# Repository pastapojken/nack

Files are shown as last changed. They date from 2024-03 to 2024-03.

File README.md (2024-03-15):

# nack
nack keyboard - uses [**QMK**](https://github.com/qmk/qmk_firmware)  
A ISO-friendly, 13x4 keyboard. It has hardware support for basically all the bells and whistles that qmk can provide!

You like my work? Feel free to donate :)  
[donation](https://www.paypal.com/donate?hosted_button_id=YEAQ4WGKJKYQQ)

nack_rgb nack with full RGB

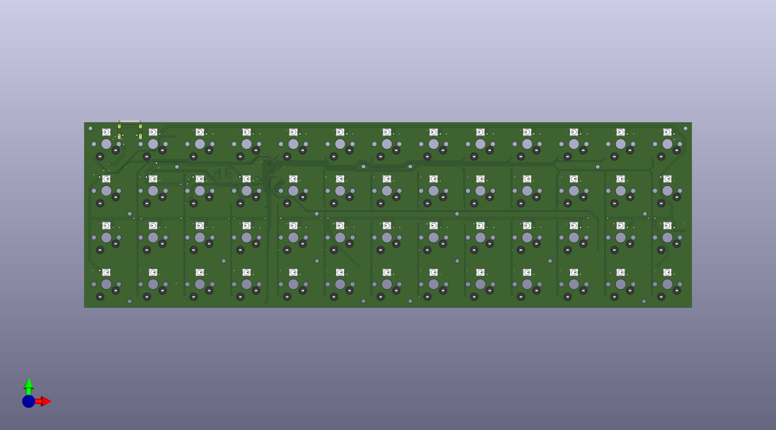
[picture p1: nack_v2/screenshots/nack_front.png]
nack_PCB_front nack PCB (front)


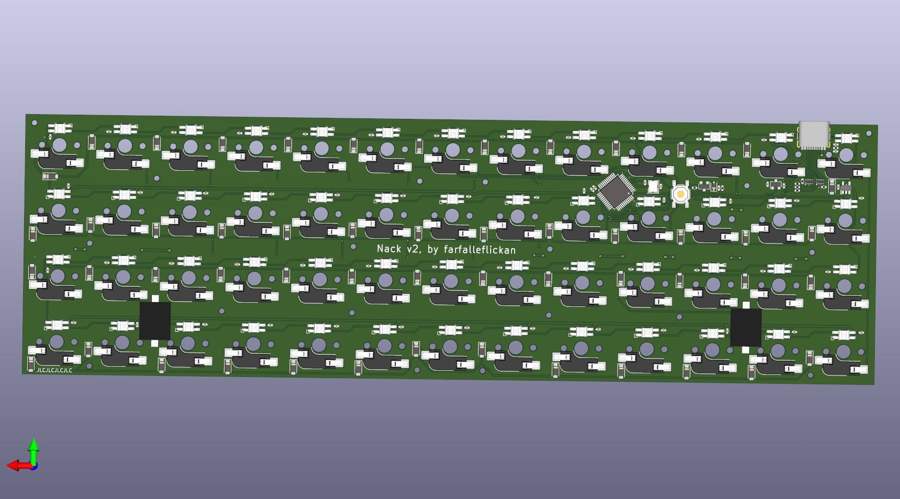
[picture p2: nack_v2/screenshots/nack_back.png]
nack_PCB_back nack PCB (back)


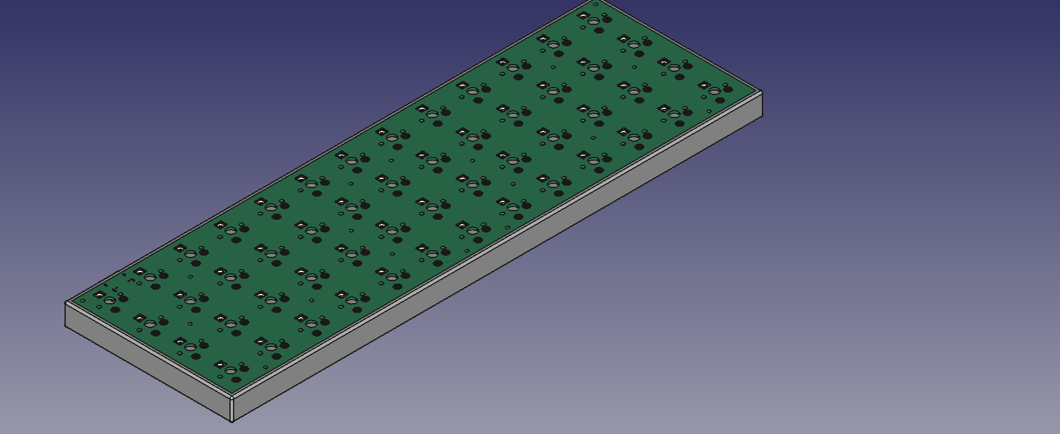
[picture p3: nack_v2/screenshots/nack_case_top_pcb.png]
nack_case_front nack case front


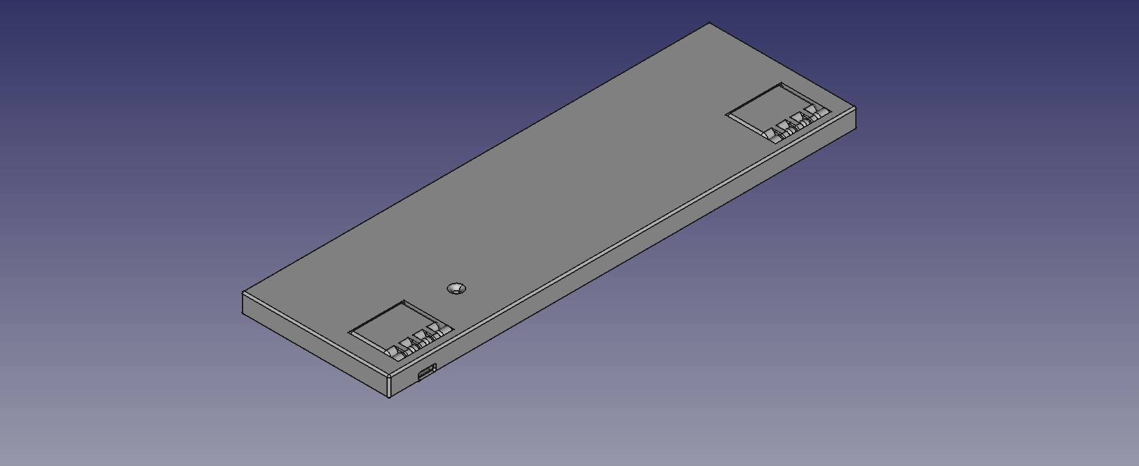
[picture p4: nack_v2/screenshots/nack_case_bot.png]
nack_case_back nack case back


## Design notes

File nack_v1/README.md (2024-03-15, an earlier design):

# nack
nack keyboard - uses [**QMK**](https://github.com/qmk/qmk_firmware)  
A ISO-friendly, 13x4 keyboard. It has hardware support for basically all the bells and whistles that qmk can provide!

You like my work? Feel free to donate :)  
[donation](https://www.paypal.com/donate?hosted_button_id=YEAQ4WGKJKYQQ)

nack_rgb nack with full RGB

nack_PCB nack PCB

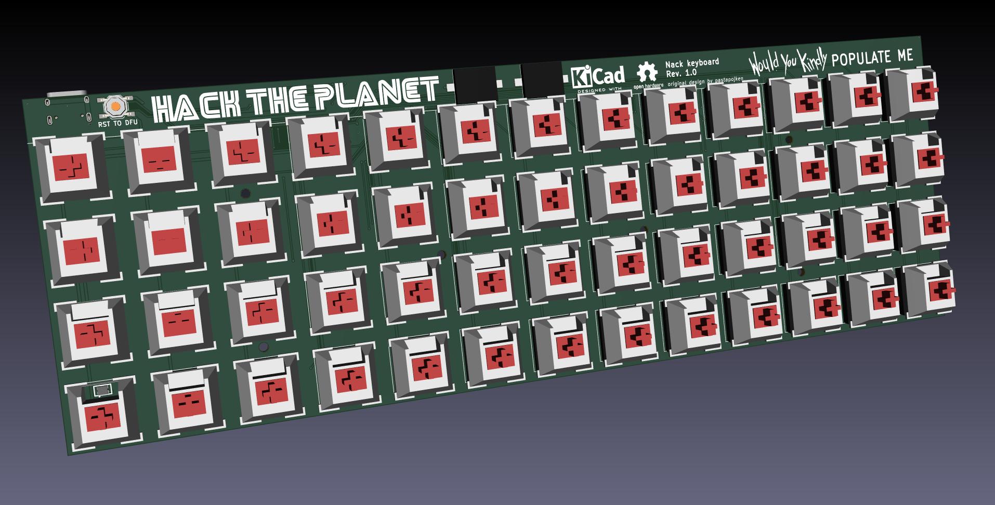
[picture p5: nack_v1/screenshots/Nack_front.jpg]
nack_front nack front


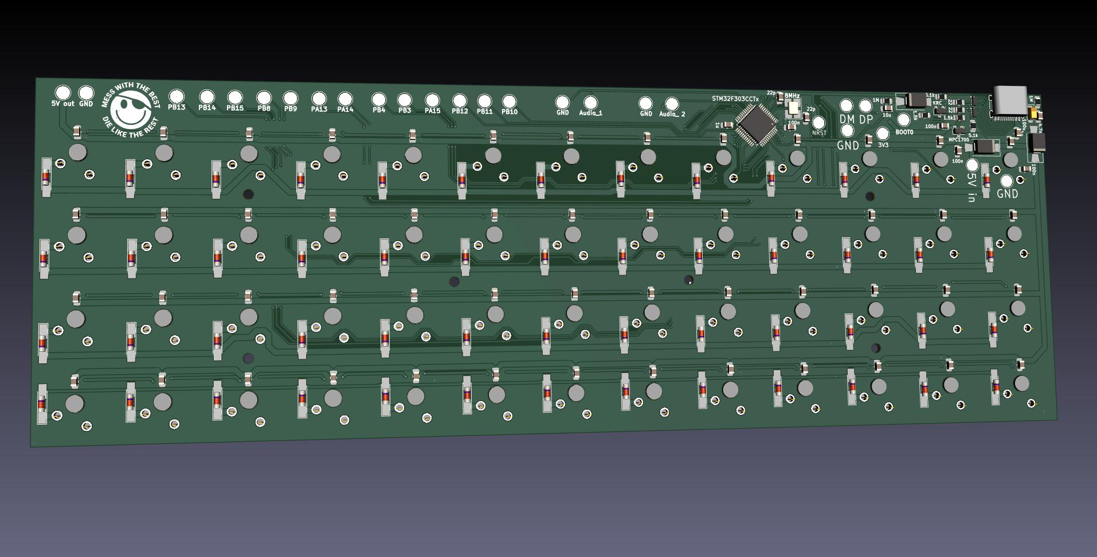
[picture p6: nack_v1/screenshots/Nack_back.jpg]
nack_back nack back


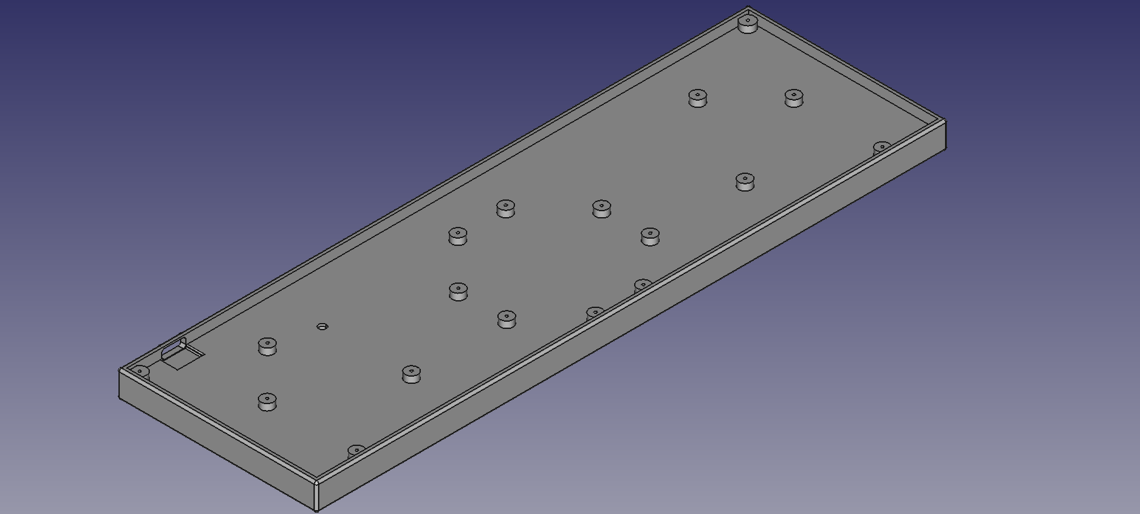
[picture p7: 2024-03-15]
nack_v2/screenshots/nack_case_top.png

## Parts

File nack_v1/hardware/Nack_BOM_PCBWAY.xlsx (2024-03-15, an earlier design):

 |  |  | Nack BOM
Item # | *Designator | *Qty | Manufacturer | *Mfg Part # | Description / Value | *Package/Footprint | Type | Your Instructions / Notes
1 | C53 C56 | 2 | Samsung Electro-Mechanics | CL21C220JBANNNC | 50V, 22pF, ceramic capacitor, 0805 | 0805 | SMD | Any manufacturer can be used, as long as the components has the same values
2 | C57 C55 C54 C1 C2 C3 C4 C5 C6 C7 C8 C9 C10 C11 C12 C13 C14 C15 C16 C17 C18 C19 C20 C21 C22 C23 C24 C25 C26 C27 C28 C29 C30 C31 C32 C33 C34 C35 C36 C37 C38 C39 C40 C41 C42 C43 C44 C45 C46 C47 C48 C49 C50 C51 C52 C60 | 56 | Samsung Electro-Mechanics | CL21B104KBCNNNC | 50V, 100nF, ceramic capacitor, 0805 | 0805 | SMD | Any manufacturer can be used, as long as the components has the same values
3 | C58 C59 | 2 | Samsung Electro-Mechanics | CL21B105KBFNNNE | 50V, 1uF, ceramic capacitor, 0805 | 0805 | SMD | Any manufacturer can be used, as long as the components has the same values
4 | C61 | 1 | Samsung Electro-Mechanics | CL21A106KQFNNNE | 6.3V, 10uF, ceramic capacitor, 0805 | 0805 | SMD | Any manufacturer can be used, as long as the components has the same values
5 | C62 | 1 | KEMET | T490A107M006ATE800 | 6.3V, 100uF, tantalum capacitor, KEMET-A/EIA-3216 | KEMET-A/EIA-3216 | SMD | Any manufacturer can be used, as long as the components has the same values
6 | C63 | 1 | CCTC | TCC0805X7R472K500DT | 50V, 4.7nF, ceramic capacitor, 0805 | 0805 | SMD | Any manufacturer can be used, as long as the components has the same values
7 | D1 D2 D3 D4 D5 D6 D7 D8 D9 D10 D11 D12 D13 D15 D16 D17 D18 D19 D20 D21 D22 D23 D24 D25 D26 D27 D28 D29 D30 D31 D32 D33 D34 D35 D36 D37 D38 D39 D40 D41 D42 D43 D44 D45 D46 D47 D48 D49 D50 D51 D52 D53 | 52 | LGE | LL4148 | LL4148, MiniMELF | MiniMELF | SMD
8 | D55 D54 D14 | 3 | Microdiode Electronics | SL54B | 40V, SL54B, SMB/DO-214AA | SMB/DO-214AA | SMD
9 | D56 D57 | 2 | Texas Instruments | TPD4E02B04DQAR | TPD4E02B04DQAR, USB ESD protection diode, uSON-10 | uSON-10 | SMD
10 | J3 | 1 | SHOU HAN | TYPE-C16PIN | USB-C receptacle with only USB2.0, mixed SMD&TH | SMD | SMD
11 | LED52 LED51 LED50 LED49 LED48 LED47 LED46 LED45 LED44 LED43 LED41 LED40 LED26 LED25 LED24 LED23 LED22 LED21 LED20 LED19 LED18 LED17 LED16 LED15 LED14 LED39 LED38 LED37 LED36 LED35 LED34 LED33 LED32 LED31 LED30 LED29 LED28 LED27 LED13 LED12 LED11 LED10 LED9 LED8 LED7 LED6 LED5 LED4 LED3 LED2 LED1 LED42 | 52 | Worldsemi | WS2812C-2020 | WS2812C LED, 2022 | 2022 | SMD
12 | LS2 LS1 | 2 | KELIKING | KLJ-1102 | NO piezo, size 11mm x 9mm, SMD-11*9*1.7 | SMD-11*9*1.7 | SMD
13 | Q1 | 1 | KEC Semicon | KRC106S-RTK/P | 50V, 200mW, Pre-Biased 100mA NPN transistor, SOT-23-3 | SOT-23 | SMD
14 | R1 R8 | 2 | Uniroyal Elec | 0805WAD | 1MΩ, ±1%, 1/8W, 0805 | 0805 | SMD | Any manufacturer can be used, as long as the components has the same values
15 | R3 R2 | 2 | Uniroyal Elec | 0805WAD | 5.1kΩ, ±1%, 1/8W, 0805 | 0805 | SMD | Any manufacturer can be used, as long as the components has the same values
16 | R5 R4 | 2 | Uniroyal Elec | 0805WAD | 22Ω, ±1%, 1/8W, 0805 | 0805 | SMD | Any manufacturer can be used, as long as the components has the same values
17 | R6 R7 | 2 | Uniroyal Elec | 0805WAD | 1.5kΩ, ±1%, 1/8W, 0805 | 0805 | SMD | Any manufacturer can be used, as long as the components has the same values
18 | U1 | 1 | STMicroelectronics | STM32F303CCT6 | STM32F303CCT6, microcontroller, LQFP-48_7x7mm_P0.5mm | LQFP-48 | SMD
19 | U2 | 1 | HTC Korea TAEJIN Tech | LM1108SF-3.3 | LM1108SF, linear regulator IC, 3.3V, SOT-23-3 | SOT-23 | SMD
20 | Y1 | 1 | KDS Daishinku | 1C208000CC0AA | 8MHz, ±30ppm, 8pF, 400Ω, SMD-3225 | 3225 | SMD | Any manufacturer can be used, as long as the components has the same values
 |  | 187

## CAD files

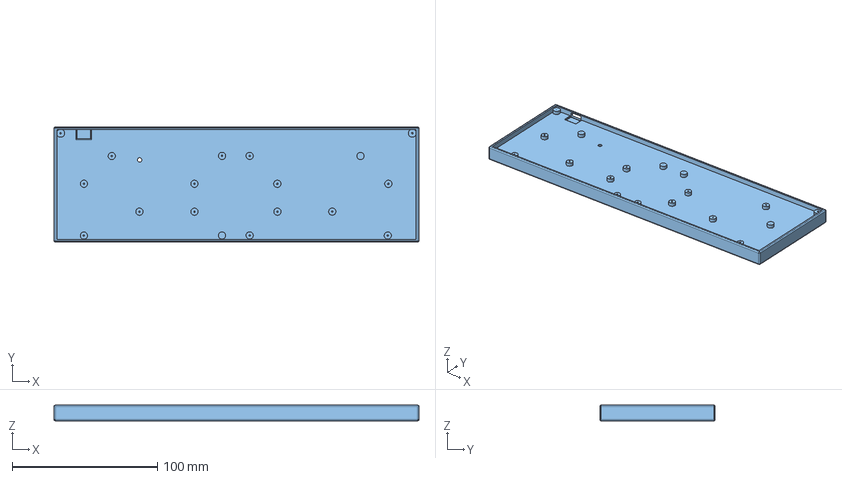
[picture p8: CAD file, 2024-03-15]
nack_v2/case/nack.FCStd
251.6 x 79.6 x 10.8 mm

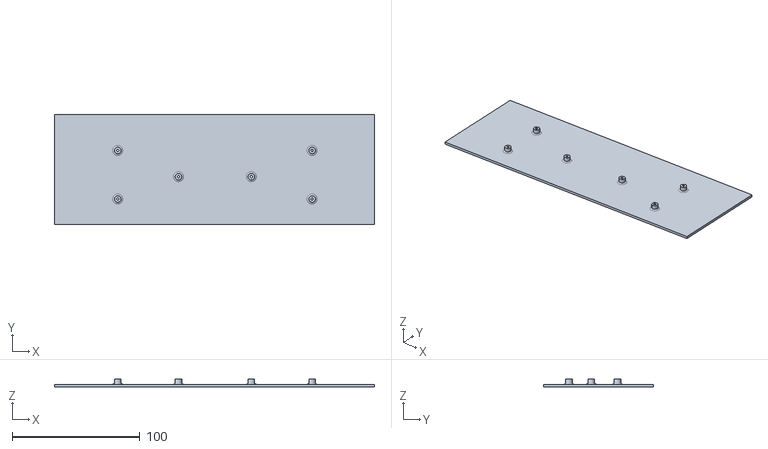
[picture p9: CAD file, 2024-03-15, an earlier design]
nack_v1/case/nackPlateBot.stl
250.9 x 86.5 x 6.00

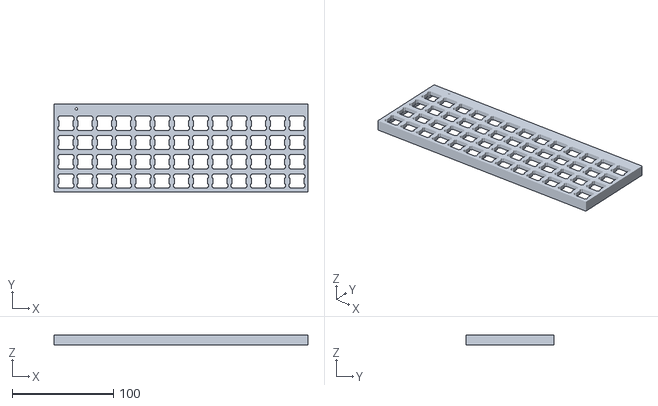
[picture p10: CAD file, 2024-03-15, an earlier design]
nack_v1/case/nackPlateTop.stl
251.3 x 86.9 x 10.2

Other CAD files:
nack_v1/case/nack_case.scad

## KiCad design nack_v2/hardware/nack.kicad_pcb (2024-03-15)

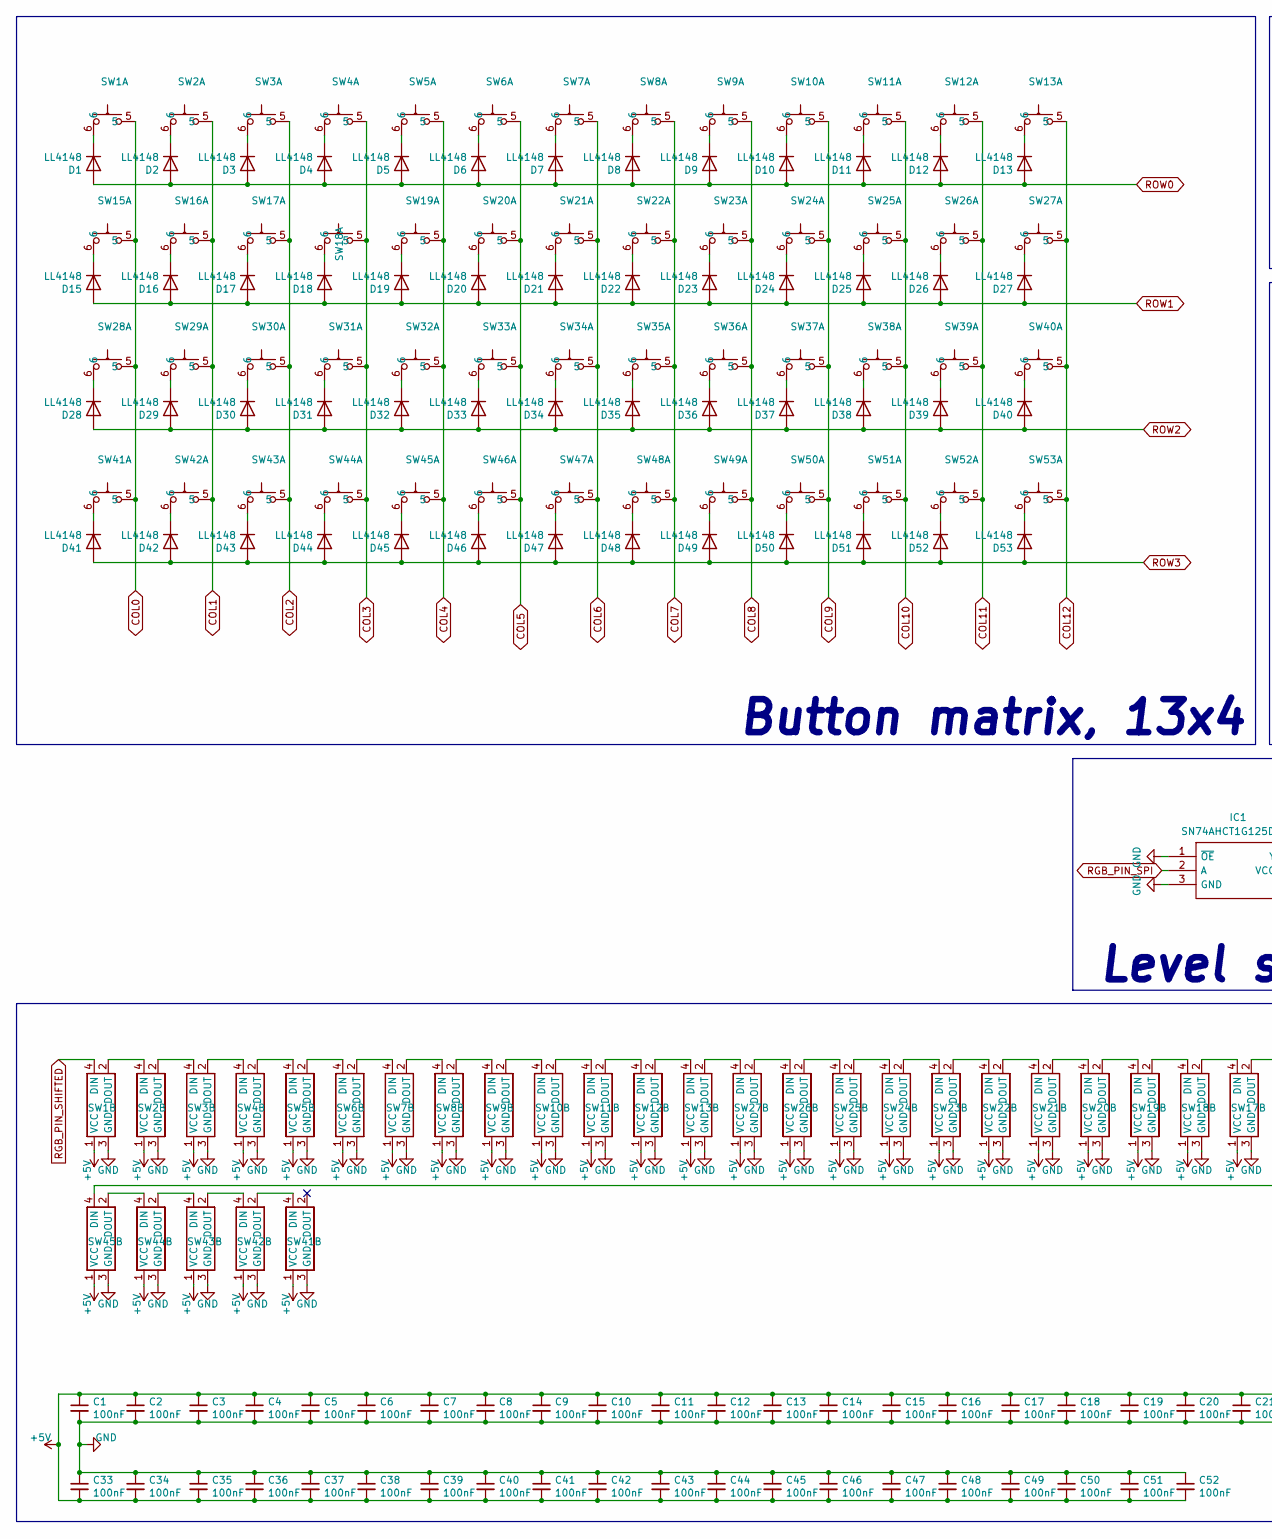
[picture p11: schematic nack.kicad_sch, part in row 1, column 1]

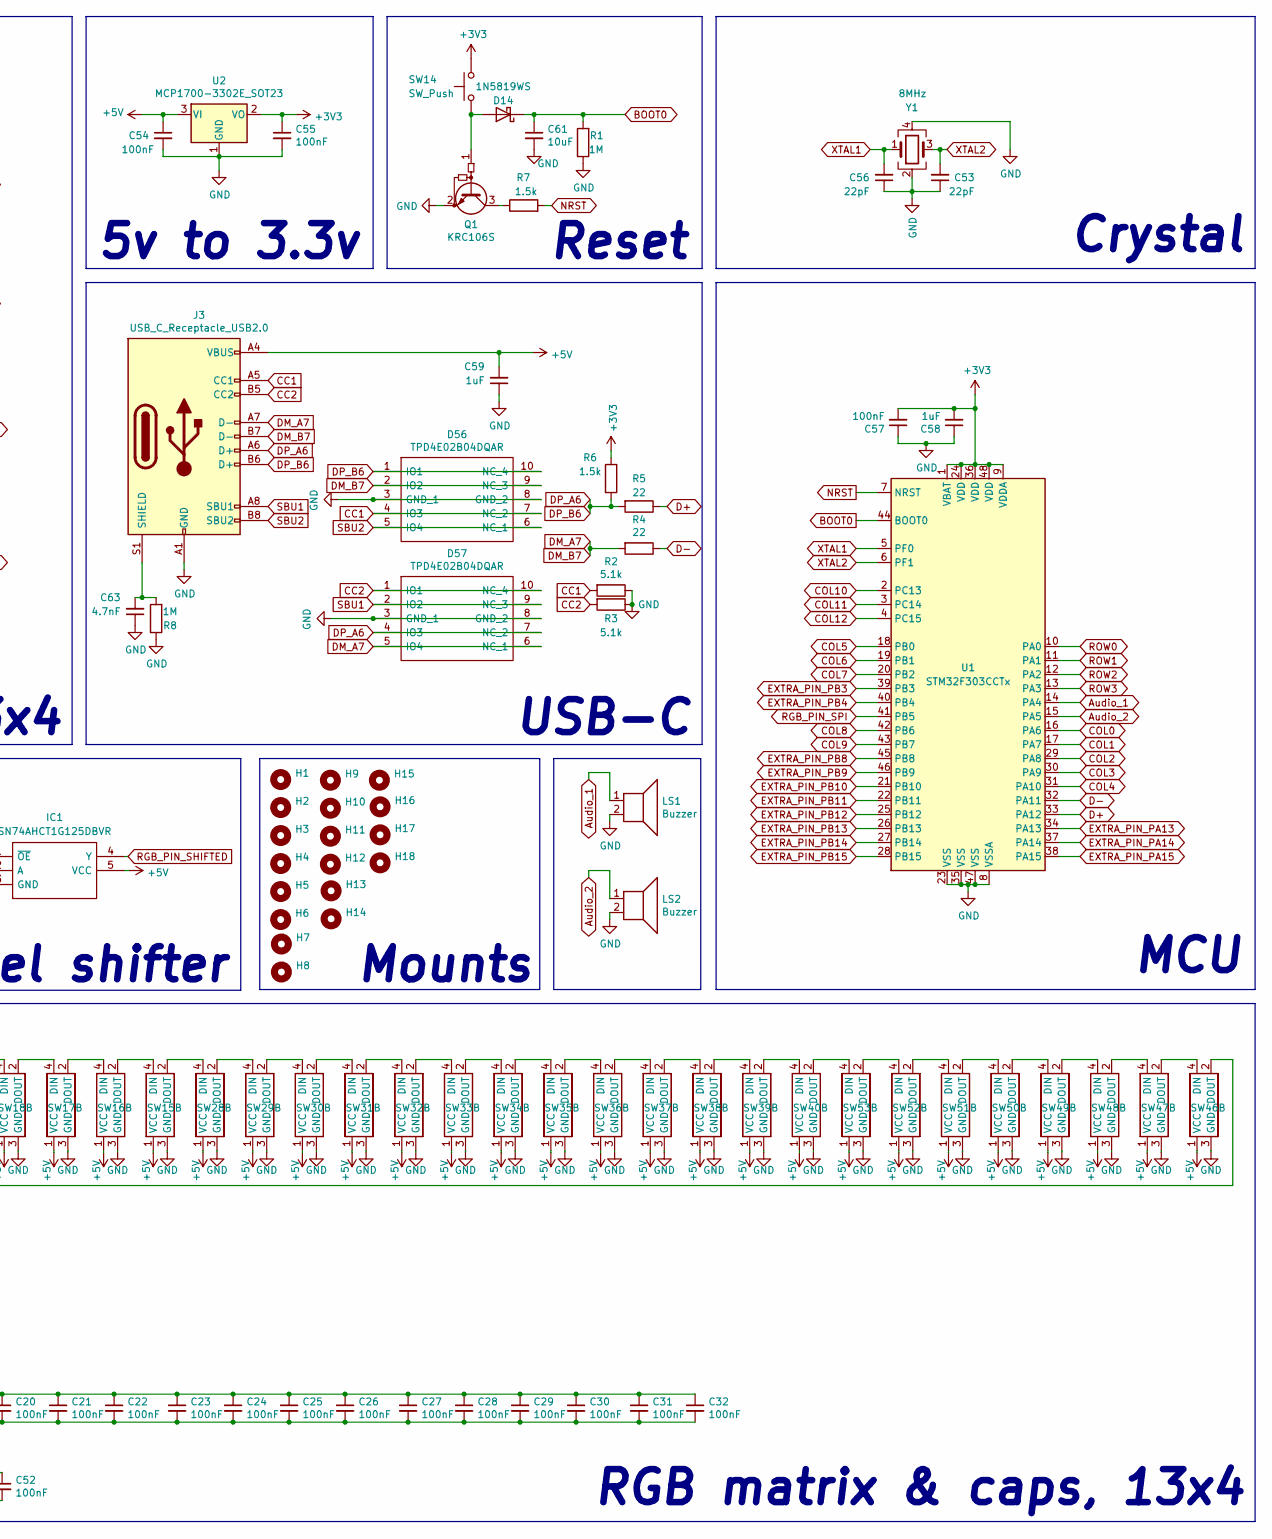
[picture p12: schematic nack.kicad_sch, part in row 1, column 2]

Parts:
C1, C2, C3, C4, C5, C6, C7, C8, C9, C10, C11, C12, C13, C14, C15, C16, C17, C18, C19, C20, C21, C22, C23, C24, C25, C26, C27, C28, C29, C30, C31, C32, C33, C34, C35, C36, C37, C38, C39, C40, C41, C42, C43, C44, C45, C46, C47, C48, C49, C50, C51, C52, C54, C55, C57: 100nF; C_0402_1005Metric
C53, C56: 22pF; C_0402_1005Metric
C58, C59: 1uF; C_0402_1005Metric
C61: 10uF; C_0402_1005Metric
C63: 4.7nF; C_0402_1005Metric
D1, D2, D3, D4, D5, D6, D7, D8, D9, D10, D11, D12, D13, D15, D16, D17, D18, D19, D20, D21, D22, D23, D24, D25, D26, D27, D28, D29, D30, D31, D32, D33, D34, D35, D36, D37, D38, D39, D40, D41, D42, D43, D44, D45, D46, D47, D48, D49, D50, D51, D52, D53: LL4148; D_SOD-123
D14: 1N5819WS; D_SOD-323
D56, D57: TPD4E02B04DQAR; DQA(R-PUSON-N10); Manufacturer_Part_Number TPD4E02B04DQAR; Mouser Part Number 595-TPD4E02B04DQAR
H1, H2, H3, H4, H5, H6, H7, H8, H9, H10, H11, H12, H13, H14, H15, H16, H17, H18: MountingHole; MountingHole_M1.4
IC1: SN74AHCT1G125DBVR; SOT95P280X145-5N; Manufacturer_Part_Number SN74AHCT1G125DBVR; Mouser Part Number 595-SNAHCT1G125DBVR
J3: USB_C_Receptacle_USB2.0; USB_C_Receptacle
LS1, LS2: Buzzer; KLJ-1102
Q1: KRC106S; SOT-23
R1, R8: 1M; R_0402_1005Metric
R2, R3: 5.1k; R_0402_1005Metric
R4, R5: 22; R_0402_1005Metric
R6, R7: 1.5k; R_0402_1005Metric
SW1, SW2, SW3, SW4, SW5, SW6, SW7, SW8, SW9, SW10, SW11, SW12, SW13, SW28, SW29, SW30, SW31, SW32, SW33, SW34, SW35, SW36, SW37, SW38, SW39, SW40: SW_Hotswap_MX; SW_Cherry_MX_Hotswap_RevLED_flipped
SW14: SW_Push; SW_SPST_TL3342
SW15, SW16, SW17, SW18, SW19, SW20, SW21, SW22, SW23, SW24, SW25, SW26, SW27, SW41, SW42, SW43, SW44, SW45, SW46, SW47, SW48, SW49, SW50, SW51, SW52, SW53: SW_Hotswap_MX; SW_Cherry_MX_Hotswap_RevLED
U1: STM32F303CCTx; LQFP-48_7x7mm_P0.5mm; LCSC C81523
U2: MCP1700-3302E_SOT23; SOT-23
Y1: 8MHz; Crystal_SMD_3225-4Pin_3.2x2.5mm; LCSC C253751

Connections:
+3V3: C55.1, C57.2, C58.2, R6.1, SW14.2, U1.1 (VBAT), U1.9 (VDDA), U1.24 (VDD), U1.36 (VDD), U1.48 (VDD), U2.2 (VO)
+5V: C1.1, C2.1, C3.1, C4.1, C5.1, C6.1, C7.1, C8.1, C9.1, C10.1, C11.1, C12.1, C13.1, C14.1, C15.1, C16.1, C17.1, C18.1, C19.1, C20.1, C21.1, C22.1, C23.1, C24.1, C25.1, C26.1, C27.1, C28.1, C29.1, C30.1, C31.1, C32.1, C33.2, C34.2, C35.2, C36.2, C37.2, C38.2, C39.2, C40.2, C41.2, C42.2, C43.2, C44.2, C45.2, C46.2, C47.2, C48.2, C49.2, C50.2, C51.2, C52.2, C54.1, C59.2, IC1.5 (VCC), J3.A4 (VBUS), J3.A9 (VBUS), J3.B4 (VBUS), J3.B9 (VBUS), SW1.1 (VCC), SW2.1 (VCC), SW3.1 (VCC), SW4.1 (VCC), SW5.1 (VCC), SW6.1 (VCC), SW7.1 (VCC), SW8.1 (VCC), SW9.1 (VCC), SW10.1 (VCC), SW11.1 (VCC), SW12.1 (VCC), SW13.1 (VCC), SW15.1 (VCC), SW16.1 (VCC), SW17.1 (VCC), SW18.1 (VCC), SW19.1 (VCC), SW20.1 (VCC), SW21.1 (VCC), SW22.1 (VCC), SW23.1 (VCC), SW24.1 (VCC), SW25.1 (VCC), SW26.1 (VCC), SW27.1 (VCC), SW28.1 (VCC), SW29.1 (VCC), SW30.1 (VCC), SW31.1 (VCC), SW32.1 (VCC), SW33.1 (VCC), SW34.1 (VCC), SW35.1 (VCC), SW36.1 (VCC), SW37.1 (VCC), SW38.1 (VCC), SW39.1 (VCC), SW40.1 (VCC), SW41.1 (VCC), SW42.1 (VCC), SW43.1 (VCC), SW44.1 (VCC), SW45.1 (VCC), SW46.1 (VCC), SW47.1 (VCC), SW48.1 (VCC), SW49.1 (VCC), SW50.1 (VCC), SW51.1 (VCC), SW52.1 (VCC), SW53.1 (VCC), U2.3 (VI)
Audio_1: LS1.1, U1.14 (PA4)
Audio_2: LS2.1, U1.15 (PA5)
BOOT0: C61.1, D14.1 (K), R1.2, U1.44 (BOOT0)
CC1: D56.4 (IO3), D56.7 (NC_2), J3.A5 (CC1), R2.2
CC2: D57.1 (IO1), D57.10 (NC_4), J3.B5 (CC2), R3.2
COL0: SW1.5, SW15.5, SW28.5, SW41.5, U1.16 (PA6)
COL1: SW2.5, SW16.5, SW29.5, SW42.5, U1.17 (PA7)
COL2: SW3.5, SW17.5, SW30.5, SW43.5, U1.29 (PA8)
COL3: SW4.5, SW18.5, SW31.5, SW44.5, U1.30 (PA9)
COL4: SW5.5, SW19.5, SW32.5, SW45.5, U1.31 (PA10)
COL5: SW6.5, SW20.5, SW33.5, SW46.5, U1.18 (PB0)
COL6: SW7.5, SW21.5, SW34.5, SW47.5, U1.19 (PB1)
COL7: SW8.5, SW22.5, SW35.5, SW48.5, U1.20 (PB2)
COL8: SW9.5, SW23.5, SW36.5, SW49.5, U1.42 (PB6)
COL9: SW10.5, SW24.5, SW37.5, SW50.5, U1.43 (PB7)
COL10: SW11.5, SW25.5, SW38.5, SW51.5, U1.2 (PC13)
COL11: SW12.5, SW26.5, SW39.5, SW52.5, U1.3 (PC14)
COL12: SW13.5, SW27.5, SW40.5, SW53.5, U1.4 (PC15)
D+: R5.1, U1.33 (PA12)
D-: R4.1, U1.32 (PA11)
DM_A7: D56.2 (IO2), D56.9 (NC_3), D57.5 (IO4), D57.6 (NC_1), J3.A7 (D-), J3.B7 (D-), R4.2
DP_A6: D56.1 (IO1), D56.10 (NC_4), D57.4 (IO3), D57.7 (NC_2), J3.A6 (D+), J3.B6 (D+), R5.2, R6.2
EXTRA_PIN_PA13: U1.34 (PA13)
EXTRA_PIN_PA14: U1.37 (PA14)
EXTRA_PIN_PA15: U1.38 (PA15)
EXTRA_PIN_PB3: U1.39 (PB3)
EXTRA_PIN_PB4: U1.40 (PB4)
EXTRA_PIN_PB8: U1.45 (PB8)
EXTRA_PIN_PB9: U1.46 (PB9)
EXTRA_PIN_PB10: U1.21 (PB10)
EXTRA_PIN_PB11: U1.22 (PB11)
EXTRA_PIN_PB12: U1.25 (PB12)
EXTRA_PIN_PB13: U1.26 (PB13)
EXTRA_PIN_PB14: U1.27 (PB14)
EXTRA_PIN_PB15: U1.28 (PB15)
GND: C1.2, C2.2, C3.2, C4.2, C5.2, C6.2, C7.2, C8.2, C9.2, C10.2, C11.2, C12.2, C13.2, C14.2, C15.2, C16.2, C17.2, C18.2, C19.2, C20.2, C21.2, C22.2, C23.2, C24.2, C25.2, C26.2, C27.2, C28.2, C29.2, C30.2, C31.2, C32.2, C33.1, C34.1, C35.1, C36.1, C37.1, C38.1, C39.1, C40.1, C41.1, C42.1, C43.1, C44.1, C45.1, C46.1, C47.1, C48.1, C49.1, C50.1, C51.1, C52.1, C53.1, C54.2, C55.2, C56.1, C57.1, C58.1, C59.1, C61.2, C63.1, D56.3 (GND_1), D56.8 (GND_2), D57.3 (GND_1), D57.8 (GND_2), IC1.1 (~OE), IC1.3 (GND), J3.A1 (GND), J3.A12 (GND), J3.B1 (GND), J3.B12 (GND), LS1.2, LS2.2, Q1.2 (E), R1.1, R2.1, R3.1, R8.1, SW1.3 (GND), SW2.3 (GND), SW3.3 (GND), SW4.3 (GND), SW5.3 (GND), SW6.3 (GND), SW7.3 (GND), SW8.3 (GND), SW9.3 (GND), SW10.3 (GND), SW11.3 (GND), SW12.3 (GND), SW13.3 (GND), SW15.3 (GND), SW16.3 (GND), SW17.3 (GND), SW18.3 (GND), SW19.3 (GND), SW20.3 (GND), SW21.3 (GND), SW22.3 (GND), SW23.3 (GND), SW24.3 (GND), SW25.3 (GND), SW26.3 (GND), SW27.3 (GND), SW28.3 (GND), SW29.3 (GND), SW30.3 (GND), SW31.3 (GND), SW32.3 (GND), SW33.3 (GND), SW34.3 (GND), SW35.3 (GND), SW36.3 (GND), SW37.3 (GND), SW38.3 (GND), SW39.3 (GND), SW40.3 (GND), SW41.3 (GND), SW42.3 (GND), SW43.3 (GND), SW44.3 (GND), SW45.3 (GND), SW46.3 (GND), SW47.3 (GND), SW48.3 (GND), SW49.3 (GND), SW50.3 (GND), SW51.3 (GND), SW52.3 (GND), SW53.3 (GND), U1.8 (VSSA), U1.23 (VSS), U1.35 (VSS), U1.47 (VSS), U2.1 (GND), Y1.2, Y1.4
NRST: R7.2, U1.7 (NRST)
unnamed: D1.1 (K), SW1.6
unnamed: D2.1 (K), SW2.6
unnamed: D3.1 (K), SW3.6
unnamed: D4.1 (K), SW4.6
unnamed: D5.1 (K), SW5.6
unnamed: D6.1 (K), SW6.6
unnamed: D7.1 (K), SW7.6
unnamed: D8.1 (K), SW8.6
unnamed: D9.1 (K), SW9.6
unnamed: D10.1 (K), SW10.6
unnamed: D11.1 (K), SW11.6
unnamed: D12.1 (K), SW12.6
unnamed: D13.1 (K), SW13.6
unnamed: D14.2 (A), Q1.1 (B), SW14.1
unnamed: D15.1 (K), SW15.6
unnamed: D16.1 (K), SW16.6
unnamed: D17.1 (K), SW17.6
unnamed: D18.1 (K), SW18.6
unnamed: D19.1 (K), SW19.6
unnamed: D20.1 (K), SW20.6
unnamed: D21.1 (K), SW21.6
unnamed: D22.1 (K), SW22.6
unnamed: D23.1 (K), SW23.6
unnamed: D24.1 (K), SW24.6
unnamed: D25.1 (K), SW25.6
unnamed: D26.1 (K), SW26.6
unnamed: D27.1 (K), SW27.6
unnamed: D28.1 (K), SW28.6
unnamed: D29.1 (K), SW29.6
unnamed: D30.1 (K), SW30.6
unnamed: D31.1 (K), SW31.6
unnamed: D32.1 (K), SW32.6
unnamed: D33.1 (K), SW33.6
unnamed: D34.1 (K), SW34.6
unnamed: D35.1 (K), SW35.6
unnamed: D36.1 (K), SW36.6
unnamed: D37.1 (K), SW37.6
unnamed: D38.1 (K), SW38.6
unnamed: D39.1 (K), SW39.6
unnamed: D40.1 (K), SW40.6
unnamed: D41.1 (K), SW41.6
unnamed: D42.1 (K), SW42.6
unnamed: D43.1 (K), SW43.6
unnamed: D44.1 (K), SW44.6
unnamed: D45.1 (K), SW45.6
unnamed: D46.1 (K), SW46.6
unnamed: D47.1 (K), SW47.6
unnamed: D48.1 (K), SW48.6
unnamed: D49.1 (K), SW49.6
unnamed: D50.1 (K), SW50.6
unnamed: D51.1 (K), SW51.6
unnamed: D52.1 (K), SW52.6
unnamed: D53.1 (K), SW53.6
unnamed: C63.2, J3.S1 (SHIELD), R8.2
unnamed: Q1.3 (C), R7.1
unnamed: SW1.2 (DOUT), SW2.4 (DIN)
unnamed: SW2.2 (DOUT), SW3.4 (DIN)
unnamed: SW3.2 (DOUT), SW4.4 (DIN)
unnamed: SW4.2 (DOUT), SW5.4 (DIN)
unnamed: SW5.2 (DOUT), SW6.4 (DIN)
unnamed: SW6.2 (DOUT), SW7.4 (DIN)
unnamed: SW7.2 (DOUT), SW8.4 (DIN)
unnamed: SW8.2 (DOUT), SW9.4 (DIN)
unnamed: SW9.2 (DOUT), SW10.4 (DIN)
unnamed: SW10.2 (DOUT), SW11.4 (DIN)
unnamed: SW11.2 (DOUT), SW12.4 (DIN)
unnamed: SW12.2 (DOUT), SW13.4 (DIN)
unnamed: SW13.2 (DOUT), SW27.4 (DIN)
unnamed: SW15.4 (DIN), SW16.2 (DOUT)
unnamed: SW15.2 (DOUT), SW28.4 (DIN)
unnamed: SW16.4 (DIN), SW17.2 (DOUT)
unnamed: SW17.4 (DIN), SW18.2 (DOUT)
unnamed: SW18.4 (DIN), SW19.2 (DOUT)
unnamed: SW19.4 (DIN), SW20.2 (DOUT)
unnamed: SW20.4 (DIN), SW21.2 (DOUT)
unnamed: SW21.4 (DIN), SW22.2 (DOUT)
unnamed: SW22.4 (DIN), SW23.2 (DOUT)
unnamed: SW23.4 (DIN), SW24.2 (DOUT)
unnamed: SW24.4 (DIN), SW25.2 (DOUT)
unnamed: SW25.4 (DIN), SW26.2 (DOUT)
unnamed: SW26.4 (DIN), SW27.2 (DOUT)
unnamed: SW28.2 (DOUT), SW29.4 (DIN)
unnamed: SW29.2 (DOUT), SW30.4 (DIN)
unnamed: SW30.2 (DOUT), SW31.4 (DIN)
unnamed: SW31.2 (DOUT), SW32.4 (DIN)
unnamed: SW32.2 (DOUT), SW33.4 (DIN)
unnamed: SW33.2 (DOUT), SW34.4 (DIN)
unnamed: SW34.2 (DOUT), SW35.4 (DIN)
unnamed: SW35.2 (DOUT), SW36.4 (DIN)
unnamed: SW36.2 (DOUT), SW37.4 (DIN)
unnamed: SW37.2 (DOUT), SW38.4 (DIN)
unnamed: SW38.2 (DOUT), SW39.4 (DIN)
unnamed: SW39.2 (DOUT), SW40.4 (DIN)
unnamed: SW40.2 (DOUT), SW53.4 (DIN)
unnamed: SW41.4 (DIN), SW42.2 (DOUT)
unnamed: SW42.4 (DIN), SW43.2 (DOUT)
unnamed: SW43.4 (DIN), SW44.2 (DOUT)
unnamed: SW44.4 (DIN), SW45.2 (DOUT)
unnamed: SW45.4 (DIN), SW46.2 (DOUT)
unnamed: SW46.4 (DIN), SW47.2 (DOUT)
unnamed: SW47.4 (DIN), SW48.2 (DOUT)
unnamed: SW48.4 (DIN), SW49.2 (DOUT)
unnamed: SW49.4 (DIN), SW50.2 (DOUT)
unnamed: SW50.4 (DIN), SW51.2 (DOUT)
unnamed: SW51.4 (DIN), SW52.2 (DOUT)
unnamed: SW52.4 (DIN), SW53.2 (DOUT)
RGB_PIN_SHIFTED: IC1.4 (Y), SW1.4 (DIN)
RGB_PIN_SPI: IC1.2 (A), U1.41 (PB5)
ROW0: D1.2 (A), D2.2 (A), D3.2 (A), D4.2 (A), D5.2 (A), D6.2 (A), D7.2 (A), D8.2 (A), D9.2 (A), D10.2 (A), D11.2 (A), D12.2 (A), D13.2 (A), U1.10 (PA0)
ROW1: D15.2 (A), D16.2 (A), D17.2 (A), D18.2 (A), D19.2 (A), D20.2 (A), D21.2 (A), D22.2 (A), D23.2 (A), D24.2 (A), D25.2 (A), D26.2 (A), D27.2 (A), U1.11 (PA1)
ROW2: D28.2 (A), D29.2 (A), D30.2 (A), D31.2 (A), D32.2 (A), D33.2 (A), D34.2 (A), D35.2 (A), D36.2 (A), D37.2 (A), D38.2 (A), D39.2 (A), D40.2 (A), U1.12 (PA2)
ROW3: D41.2 (A), D42.2 (A), D43.2 (A), D44.2 (A), D45.2 (A), D46.2 (A), D47.2 (A), D48.2 (A), D49.2 (A), D50.2 (A), D51.2 (A), D52.2 (A), D53.2 (A), U1.13 (PA3)
SBU1: D57.2 (IO2), D57.9 (NC_3), J3.A8 (SBU1)
SBU2: D56.5 (IO4), D56.6 (NC_1), J3.B8 (SBU2)
XTAL1: C56.2, U1.5 (PF0), Y1.1
XTAL2: C53.2, U1.6 (PF1), Y1.3

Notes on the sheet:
Mounts
USB-C
Crystal
RGB matrix & caps, 13x4
Reset
Button matrix, 13x4
5v to 3.3v
Level shifter
MCU

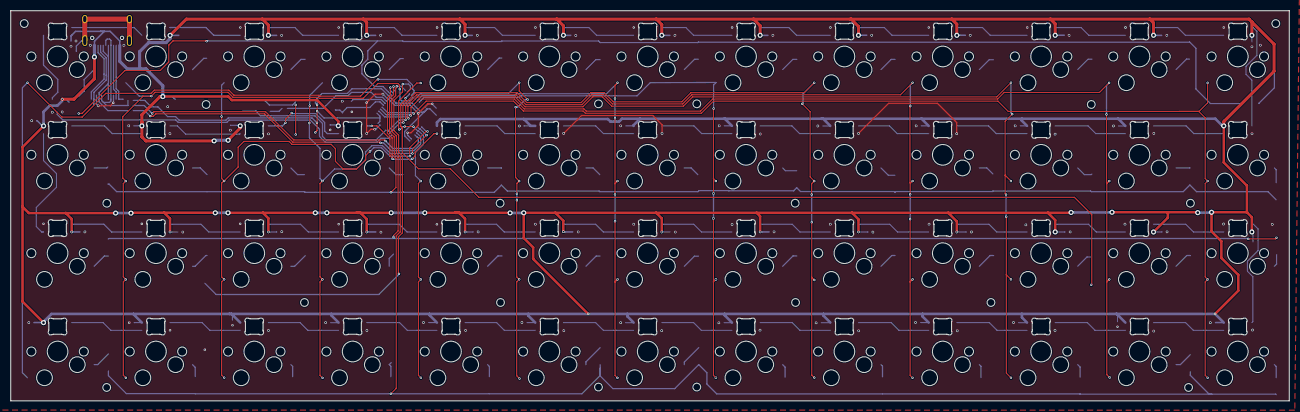
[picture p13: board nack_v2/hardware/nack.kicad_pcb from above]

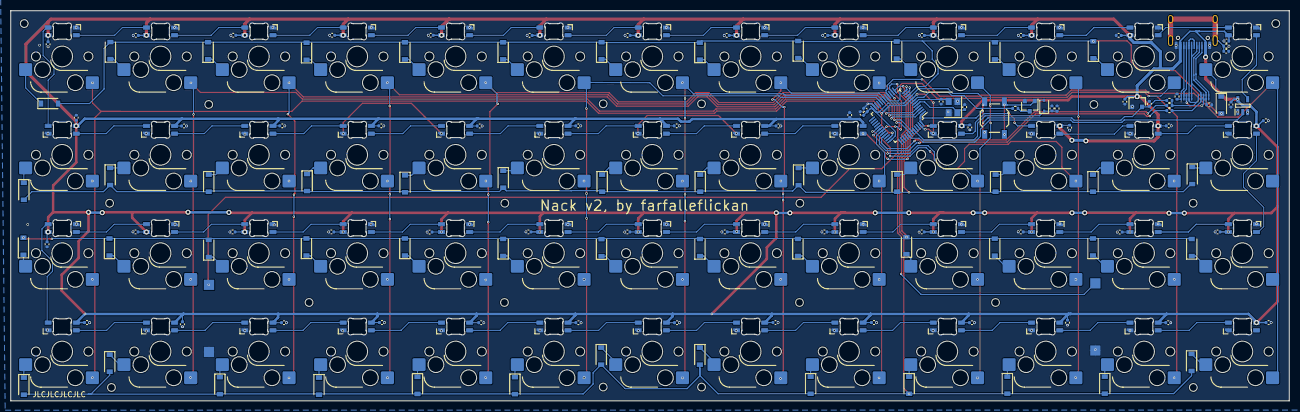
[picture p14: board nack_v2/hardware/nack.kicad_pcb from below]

Board: 2 copper layers, 247.6 x 75.6 mm, 203 parts (133 on the bottom side), 142 nets.

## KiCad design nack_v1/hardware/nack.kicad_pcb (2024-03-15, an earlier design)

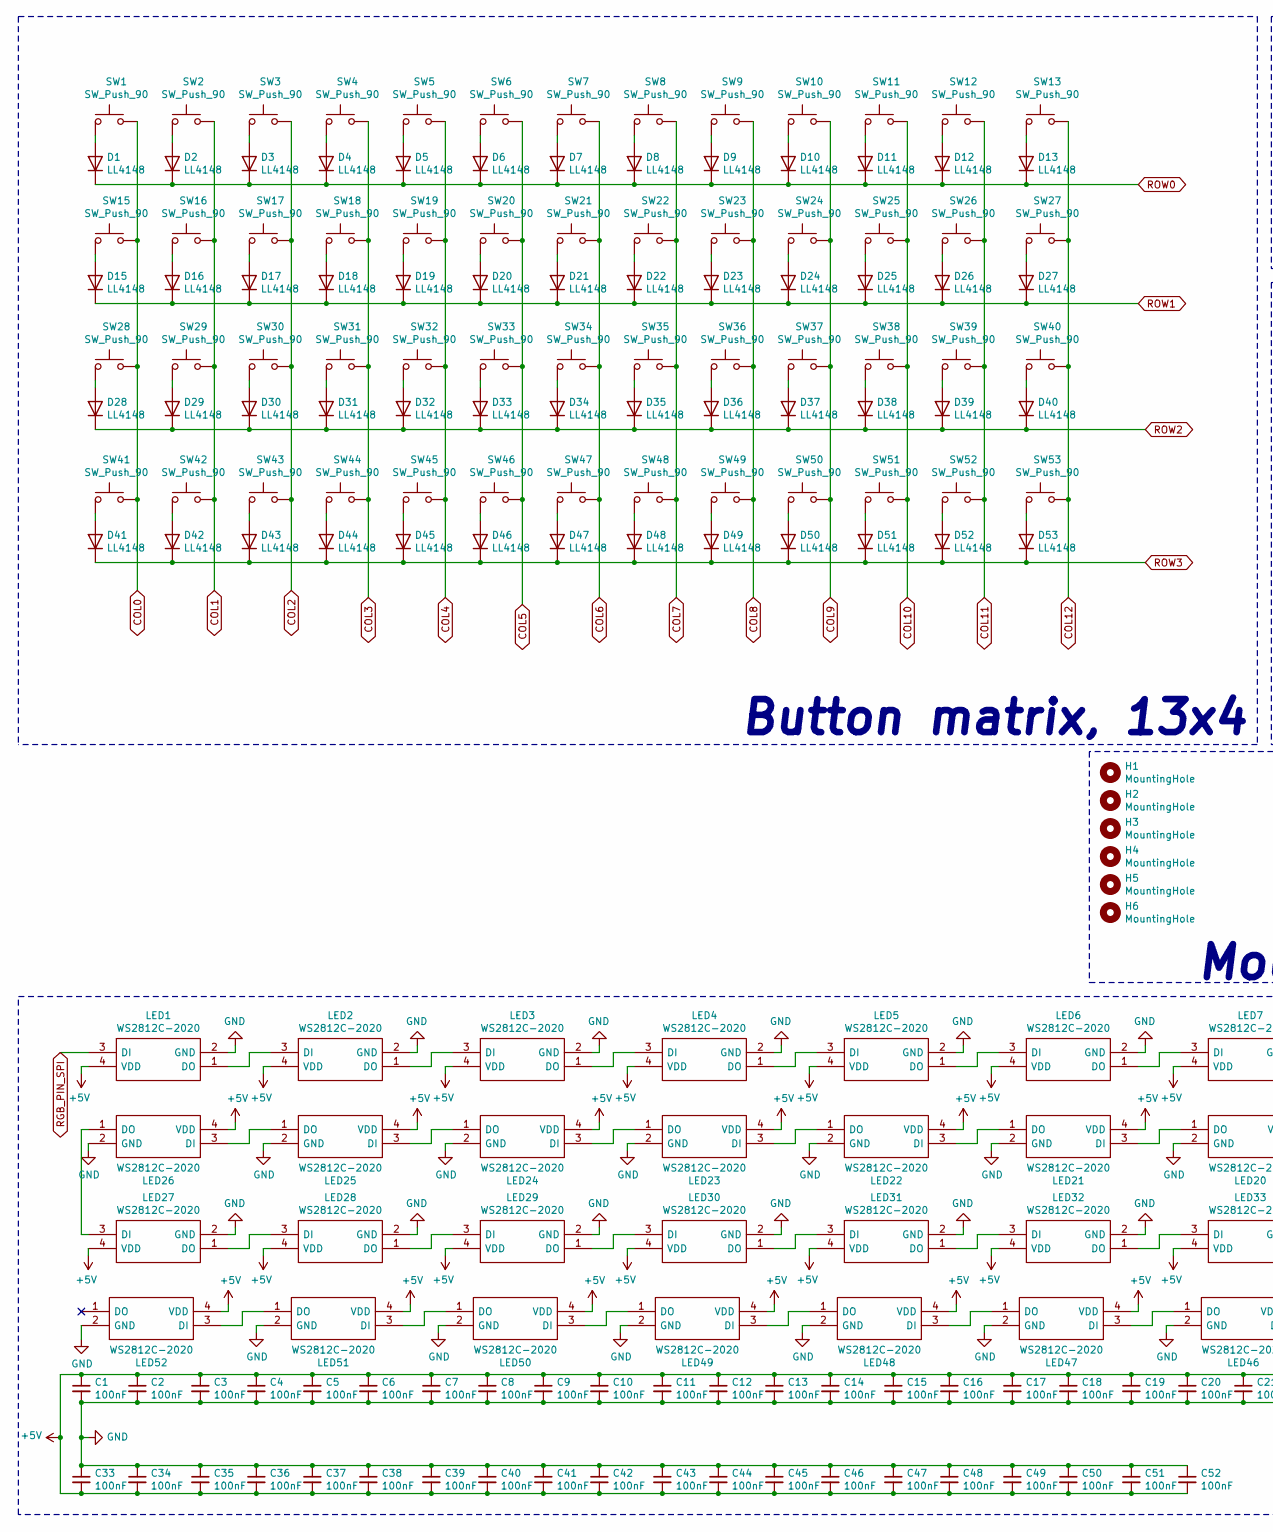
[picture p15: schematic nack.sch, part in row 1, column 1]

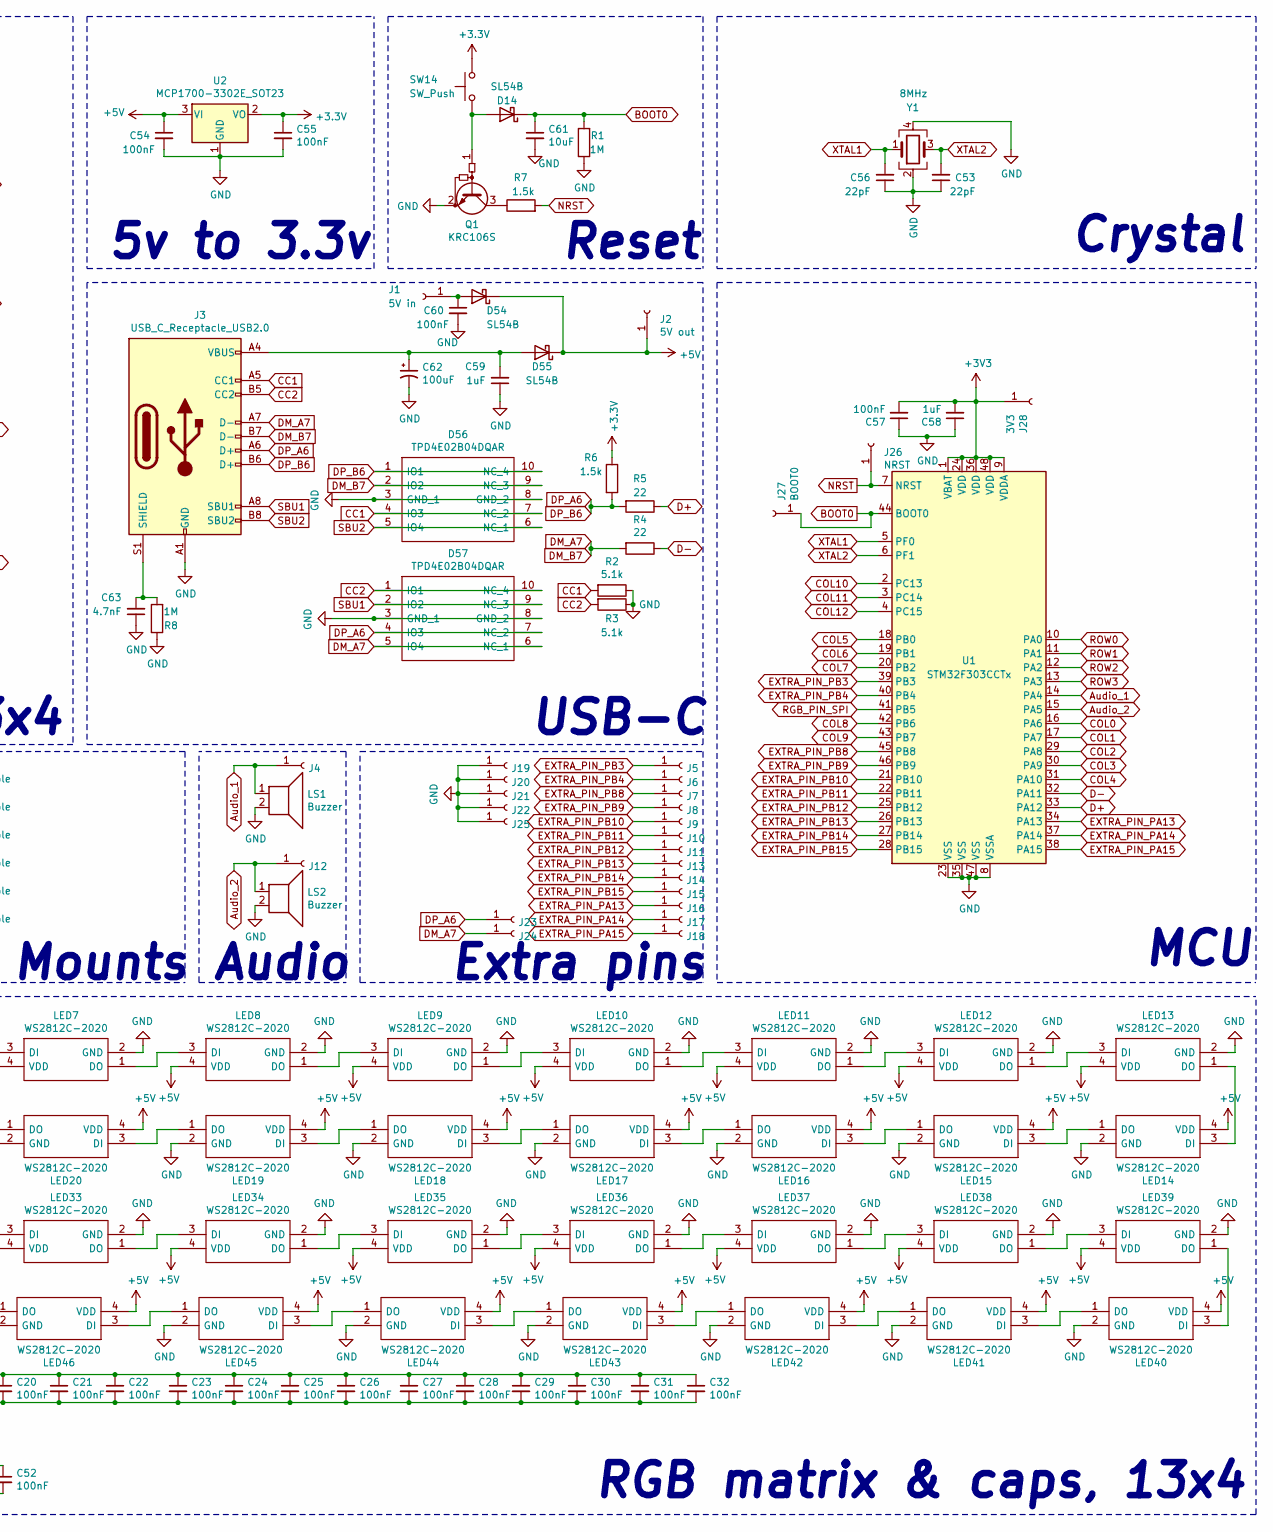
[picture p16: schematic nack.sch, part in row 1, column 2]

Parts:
C1, C2, C3, C4, C5, C6, C7, C8, C9, C10, C11, C12, C13, C14, C15, C16, C17, C18, C19, C20, C21, C22, C23, C24, C25, C26, C27, C28, C29, C30, C31, C32, C33, C34, C35, C36, C37, C38, C39, C40, C41, C42, C43, C44, C45, C46, C47, C48, C49, C50, C51, C52, C54, C55, C57, C60: 100nF; C_0805_2012Metric_Pad1.15x1.40mm_HandSolder
C53, C56: 22pF; C_0805_2012Metric_Pad1.15x1.40mm_HandSolder
C58, C59: 1uF; C_0805_2012Metric_Pad1.15x1.40mm_HandSolder
C61: 10uF; C_0805_2012Metric_Pad1.15x1.40mm_HandSolder
C62: 100uF; CP_EIA-3216-18_Kemet-A_Pad1.58x1.35mm_HandSolder
C63: 4.7nF; C_0805_2012Metric_Pad1.15x1.40mm_HandSolder
D1, D2, D3, D4, D5, D6, D7, D8, D9, D10, D11, D12, D13, D15, D16, D17, D18, D19, D20, D21, D22, D23, D24, D25, D26, D27, D28, D29, D30, D31, D32, D33, D34, D35, D36, D37, D38, D39, D40, D41, D42, D43, D44, D45, D46, D47, D48, D49, D50, D51, D52, D53: LL4148; D_MiniMELF_Handsoldering
D14, D54, D55: SL54B; D_SMA-SMB_Universal_Handsoldering
D56, D57: TPD4E02B04DQAR; DQA(R-PUSON-N10); Manufacturer_Part_Number TPD4E02B04DQAR; Mouser Part Number 595-TPD4E02B04DQAR
H1, H2, H3, H4, H5, H6: MountingHole; MountingHole_2.2mm_M2
J1: 5V in; TestPoint_Pad_D3.0mm
J2: 5V out; TestPoint_Pad_D3.0mm
J3: USB_C_Receptacle_USB2.0; USB_C_Receptacle
J4, J5, J6, J7, J8, J9, J10, J11, J12, J13, J14, J15, J16, J17, J18, J19, J20, J21, J22, J23, J24, J25: Conn_01x01_Female; TestPoint_Pad_D3.0mm
J26: NRST; TestPoint_Pad_D3.0mm
J27: BOOT0; TestPoint_Pad_D3.0mm
J28: 3V3; TestPoint_Pad_D3.0mm
LED1, LED2, LED3, LED4, LED5, LED6, LED7, LED8, LED9, LED10, LED11, LED12, LED13, LED14, LED15, LED16, LED17, LED18, LED19, LED20, LED21, LED22, LED23, LED24, LED25, LED26, LED27, LED28, LED29, LED30, LED31, LED32, LED33, LED34, LED35, LED36, LED37, LED38, LED39, LED40, LED41, LED42, LED43, LED44, LED45, LED46, LED47, LED48, LED49, LED50, LED51, LED52: WS2812C-2020; WS2812C2020; Manufacturer_Part_Number WS2812C-2020
LS1, LS2: Buzzer; KLJ-1102
Q1: KRC106S; SOT-23
R1, R8: 1M; R_0805_2012Metric_Pad1.15x1.40mm_HandSolder
R2, R3: 5.1k; R_0805_2012Metric_Pad1.15x1.40mm_HandSolder
R4, R5: 22; R_0805_2012Metric_Pad1.15x1.40mm_HandSolder
R6, R7: 1.5k; R_0805_2012Metric_Pad1.15x1.40mm_HandSolder
SW1, SW2, SW3, SW4, SW5, SW6, SW7, SW8, SW9, SW10, SW11, SW12, SW13, SW15, SW16, SW17, SW18, SW19, SW20, SW21, SW22, SW23, SW24, SW25, SW26, SW27, SW28, SW29, SW30, SW31, SW32, SW33, SW34, SW35, SW36, SW37, SW38, SW39, SW40, SW41, SW42, SW43, SW44, SW45, SW46, SW47, SW48, SW49, SW50, SW51, SW52, SW53: SW_Push_90; SW_Cherry_MX_1.00u_Plate_LED_Guide
SW14: SW_Push; SW_SPST_TL3342
U1: STM32F303CCTx; LQFP-48_7x7mm_P0.5mm; LCSC C81523
U2: MCP1700-3302E_SOT23; SOT-23
Y1: 8MHz; Crystal_SMD_3225-4Pin_3.2x2.5mm_HandSoldering; LCSC C253751

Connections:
+5V: C1.1, C2.1, C3.1, C4.1, C5.1, C6.1, C7.1, C8.1, C9.1, C10.1, C11.1, C12.1, C13.1, C14.1, C15.1, C16.1, C17.1, C18.1, C19.1, C20.1, C21.1, C22.1, C23.1, C24.1, C25.1, C26.1, C27.1, C28.1, C29.1, C30.1, C31.1, C32.1, C33.2, C34.2, C35.2, C36.2, C37.2, C38.2, C39.2, C40.2, C41.2, C42.2, C43.2, C44.2, C45.2, C46.2, C47.2, C48.2, C49.2, C50.2, C51.2, C52.2, C54.1, D54.1 (K), D55.1 (K), J2.1, LED1.4 (VDD), LED2.4 (VDD), LED3.4 (VDD), LED4.4 (VDD), LED5.4 (VDD), LED6.4 (VDD), LED7.4 (VDD), LED8.4 (VDD), LED9.4 (VDD), LED10.4 (VDD), LED11.4 (VDD), LED12.4 (VDD), LED13.4 (VDD), LED14.4 (VDD), LED15.4 (VDD), LED16.4 (VDD), LED17.4 (VDD), LED18.4 (VDD), LED19.4 (VDD), LED20.4 (VDD), LED21.4 (VDD), LED22.4 (VDD), LED23.4 (VDD), LED24.4 (VDD), LED25.4 (VDD), LED26.4 (VDD), LED27.4 (VDD), LED28.4 (VDD), LED29.4 (VDD), LED30.4 (VDD), LED31.4 (VDD), LED32.4 (VDD), LED33.4 (VDD), LED34.4 (VDD), LED35.4 (VDD), LED36.4 (VDD), LED37.4 (VDD), LED38.4 (VDD), LED39.4 (VDD), LED40.4 (VDD), LED41.4 (VDD), LED42.4 (VDD), LED43.4 (VDD), LED44.4 (VDD), LED45.4 (VDD), LED46.4 (VDD), LED47.4 (VDD), LED48.4 (VDD), LED49.4 (VDD), LED50.4 (VDD), LED51.4 (VDD), LED52.4 (VDD), U2.3 (VI)
Audio_1: J4.1, LS1.1, U1.14 (PA4)
Audio_2: J12.1, LS2.1, U1.15 (PA5)
BOOT0: C61.1, D14.1 (K), J27.1, R1.2, U1.44 (BOOT0)
CC1: D56.4 (IO3), D56.7 (NC_2), J3.A5 (CC1), R2.2
CC2: D57.1 (IO1), D57.10 (NC_4), J3.B5 (CC2), R3.2
COL0: SW1.2, SW15.2, SW28.2, SW41.2, U1.16 (PA6)
COL1: SW2.2, SW16.2, SW29.2, SW42.2, U1.17 (PA7)
COL2: SW3.2, SW17.2, SW30.2, SW43.2, U1.29 (PA8)
COL3: SW4.2, SW18.2, SW31.2, SW44.2, U1.30 (PA9)
COL4: SW5.2, SW19.2, SW32.2, SW45.2, U1.31 (PA10)
COL5: SW6.2, SW20.2, SW33.2, SW46.2, U1.18 (PB0)
COL6: SW7.2, SW21.2, SW34.2, SW47.2, U1.19 (PB1)
COL7: SW8.2, SW22.2, SW35.2, SW48.2, U1.20 (PB2)
COL8: SW9.2, SW23.2, SW36.2, SW49.2, U1.42 (PB6)
COL9: SW10.2, SW24.2, SW37.2, SW50.2, U1.43 (PB7)
COL10: SW11.2, SW25.2, SW38.2, SW51.2, U1.2 (PC13)
COL11: SW12.2, SW26.2, SW39.2, SW52.2, U1.3 (PC14)
COL12: SW13.2, SW27.2, SW40.2, SW53.2, U1.4 (PC15)
D+: R5.1, U1.33 (PA12)
D-: R4.1, U1.32 (PA11)
DM_A7: D56.2 (IO2), D56.9 (NC_3), D57.5 (IO4), D57.6 (NC_1), J3.A7 (D-), J3.B7 (D-), J24.1, R4.2
DP_A6: D56.1 (IO1), D56.10 (NC_4), D57.4 (IO3), D57.7 (NC_2), J3.A6 (D+), J3.B6 (D+), J23.1, R5.2, R6.2
EXTRA_PIN_PA13: J16.1, U1.34 (PA13)
EXTRA_PIN_PA14: J17.1, U1.37 (PA14)
EXTRA_PIN_PA15: J18.1, U1.38 (PA15)
EXTRA_PIN_PB3: J5.1, U1.39 (PB3)
EXTRA_PIN_PB4: J6.1, U1.40 (PB4)
EXTRA_PIN_PB8: J7.1, U1.45 (PB8)
EXTRA_PIN_PB9: J8.1, U1.46 (PB9)
EXTRA_PIN_PB10: J9.1, U1.21 (PB10)
EXTRA_PIN_PB11: J10.1, U1.22 (PB11)
EXTRA_PIN_PB12: J11.1, U1.25 (PB12)
EXTRA_PIN_PB13: J13.1, U1.26 (PB13)
EXTRA_PIN_PB14: J14.1, U1.27 (PB14)
EXTRA_PIN_PB15: J15.1, U1.28 (PB15)
GND: C1.2, C2.2, C3.2, C4.2, C5.2, C6.2, C7.2, C8.2, C9.2, C10.2, C11.2, C12.2, C13.2, C14.2, C15.2, C16.2, C17.2, C18.2, C19.2, C20.2, C21.2, C22.2, C23.2, C24.2, C25.2, C26.2, C27.2, C28.2, C29.2, C30.2, C31.2, C32.2, C33.1, C34.1, C35.1, C36.1, C37.1, C38.1, C39.1, C40.1, C41.1, C42.1, C43.1, C44.1, C45.1, C46.1, C47.1, C48.1, C49.1, C50.1, C51.1, C52.1, C53.1, C54.2, C55.2, C56.1, C57.1, C58.1, C59.1, C60.2, C61.2, C62.2, C63.1, D56.3 (GND_1), D56.8 (GND_2), D57.3 (GND_1), D57.8 (GND_2), J3.A1 (GND), J3.A12 (GND), J3.B1 (GND), J3.B12 (GND), J19.1, J20.1, J21.1, J22.1, J25.1, LED1.2 (GND), LED2.2 (GND), LED3.2 (GND), LED4.2 (GND), LED5.2 (GND), LED6.2 (GND), LED7.2 (GND), LED8.2 (GND), LED9.2 (GND), LED10.2 (GND), LED11.2 (GND), LED12.2 (GND), LED13.2 (GND), LED14.2 (GND), LED15.2 (GND), LED16.2 (GND), LED17.2 (GND), LED18.2 (GND), LED19.2 (GND), LED20.2 (GND), LED21.2 (GND), LED22.2 (GND), LED23.2 (GND), LED24.2 (GND), LED25.2 (GND), LED26.2 (GND), LED27.2 (GND), LED28.2 (GND), LED29.2 (GND), LED30.2 (GND), LED31.2 (GND), LED32.2 (GND), LED33.2 (GND), LED34.2 (GND), LED35.2 (GND), LED36.2 (GND), LED37.2 (GND), LED38.2 (GND), LED39.2 (GND), LED40.2 (GND), LED41.2 (GND), LED42.2 (GND), LED43.2 (GND), LED44.2 (GND), LED45.2 (GND), LED46.2 (GND), LED47.2 (GND), LED48.2 (GND), LED49.2 (GND), LED50.2 (GND), LED51.2 (GND), LED52.2 (GND), LS1.2, LS2.2, Q1.2 (E), R1.1, R2.1, R3.1, R8.1, U1.8 (VSSA), U1.23 (VSS), U1.35 (VSS), U1.47 (VSS), U2.1 (GND), Y1.2, Y1.4
NRST: J26.1, R7.2, U1.7 (NRST)
unnamed: C59.2, C62.1, D55.2 (A), J3.A4 (VBUS), J3.A9 (VBUS), J3.B4 (VBUS), J3.B9 (VBUS)
unnamed: C60.1, D54.2 (A), J1.1
unnamed: C63.2, J3.S1 (SHIELD), R8.2
unnamed: D1.2 (A), SW1.1
unnamed: D2.2 (A), SW2.1
unnamed: D3.2 (A), SW3.1
unnamed: D4.2 (A), SW4.1
unnamed: D5.2 (A), SW5.1
unnamed: D6.2 (A), SW6.1
unnamed: D7.2 (A), SW7.1
unnamed: D8.2 (A), SW8.1
unnamed: D9.2 (A), SW9.1
unnamed: D10.2 (A), SW10.1
unnamed: D11.2 (A), SW11.1
unnamed: D12.2 (A), SW12.1
unnamed: D13.2 (A), SW13.1
unnamed: D14.2 (A), Q1.1 (B), SW14.1
unnamed: D15.2 (A), SW15.1
unnamed: D16.2 (A), SW16.1
unnamed: D17.2 (A), SW17.1
unnamed: D18.2 (A), SW18.1
unnamed: D19.2 (A), SW19.1
unnamed: D20.2 (A), SW20.1
unnamed: D21.2 (A), SW21.1
unnamed: D22.2 (A), SW22.1
unnamed: D23.2 (A), SW23.1
unnamed: D24.2 (A), SW24.1
unnamed: D25.2 (A), SW25.1
unnamed: D26.2 (A), SW26.1
unnamed: D27.2 (A), SW27.1
unnamed: D28.2 (A), SW28.1
unnamed: D29.2 (A), SW29.1
unnamed: D30.2 (A), SW30.1
unnamed: D31.2 (A), SW31.1
unnamed: D32.2 (A), SW32.1
unnamed: D33.2 (A), SW33.1
unnamed: D34.2 (A), SW34.1
unnamed: D35.2 (A), SW35.1
unnamed: D36.2 (A), SW36.1
unnamed: D37.2 (A), SW37.1
unnamed: D38.2 (A), SW38.1
unnamed: D39.2 (A), SW39.1
unnamed: D40.2 (A), SW40.1
unnamed: D41.2 (A), SW41.1
unnamed: D42.2 (A), SW42.1
unnamed: D43.2 (A), SW43.1
unnamed: D44.2 (A), SW44.1
unnamed: D45.2 (A), SW45.1
unnamed: D46.2 (A), SW46.1
unnamed: D47.2 (A), SW47.1
unnamed: D48.2 (A), SW48.1
unnamed: D49.2 (A), SW49.1
unnamed: D50.2 (A), SW50.1
unnamed: D51.2 (A), SW51.1
unnamed: D52.2 (A), SW52.1
unnamed: D53.2 (A), SW53.1
unnamed: LED1.1 (DO), LED2.3 (DI)
unnamed: LED2.1 (DO), LED3.3 (DI)
unnamed: LED3.1 (DO), LED4.3 (DI)
unnamed: LED4.1 (DO), LED5.3 (DI)
unnamed: LED5.1 (DO), LED6.3 (DI)
unnamed: LED6.1 (DO), LED7.3 (DI)
unnamed: LED7.1 (DO), LED8.3 (DI)
unnamed: LED8.1 (DO), LED9.3 (DI)
unnamed: LED10.1 (DO), LED11.3 (DI)
unnamed: LED9.1 (DO), LED10.3 (DI)
unnamed: LED11.1 (DO), LED12.3 (DI)
unnamed: LED12.1 (DO), LED13.3 (DI)
unnamed: LED13.1 (DO), LED14.3 (DI)
unnamed: LED14.1 (DO), LED15.3 (DI)
unnamed: LED15.1 (DO), LED16.3 (DI)
unnamed: LED16.1 (DO), LED17.3 (DI)
unnamed: LED17.1 (DO), LED18.3 (DI)
unnamed: LED18.1 (DO), LED19.3 (DI)
unnamed: LED19.1 (DO), LED20.3 (DI)
unnamed: LED20.1 (DO), LED21.3 (DI)
unnamed: LED21.1 (DO), LED22.3 (DI)
unnamed: LED22.1 (DO), LED23.3 (DI)
unnamed: LED23.1 (DO), LED24.3 (DI)
unnamed: LED24.1 (DO), LED25.3 (DI)
unnamed: LED25.1 (DO), LED26.3 (DI)
unnamed: LED26.1 (DO), LED27.3 (DI)
unnamed: LED27.1 (DO), LED28.3 (DI)
unnamed: LED28.1 (DO), LED29.3 (DI)
unnamed: LED29.1 (DO), LED30.3 (DI)
unnamed: LED30.1 (DO), LED31.3 (DI)
unnamed: LED31.1 (DO), LED32.3 (DI)
unnamed: LED32.1 (DO), LED33.3 (DI)
unnamed: LED33.1 (DO), LED34.3 (DI)
unnamed: LED34.1 (DO), LED35.3 (DI)
unnamed: LED35.1 (DO), LED36.3 (DI)
unnamed: LED36.1 (DO), LED37.3 (DI)
unnamed: LED37.1 (DO), LED38.3 (DI)
unnamed: LED38.1 (DO), LED39.3 (DI)
unnamed: LED39.1 (DO), LED40.3 (DI)
unnamed: LED40.1 (DO), LED41.3 (DI)
unnamed: LED41.1 (DO), LED42.3 (DI)
unnamed: LED42.1 (DO), LED43.3 (DI)
unnamed: LED43.1 (DO), LED44.3 (DI)
unnamed: LED44.1 (DO), LED45.3 (DI)
unnamed: LED45.1 (DO), LED46.3 (DI)
unnamed: LED46.1 (DO), LED47.3 (DI)
unnamed: LED47.1 (DO), LED48.3 (DI)
unnamed: LED48.1 (DO), LED49.3 (DI)
unnamed: LED49.1 (DO), LED50.3 (DI)
unnamed: LED50.1 (DO), LED51.3 (DI)
unnamed: LED51.1 (DO), LED52.3 (DI)
unnamed: Q1.3 (C), R7.1
RGB_PIN_SPI: LED1.3 (DI), U1.41 (PB5)
ROW0: D1.1 (K), D2.1 (K), D3.1 (K), D4.1 (K), D5.1 (K), D6.1 (K), D7.1 (K), D8.1 (K), D9.1 (K), D10.1 (K), D11.1 (K), D12.1 (K), D13.1 (K), U1.10 (PA0)
ROW1: D15.1 (K), D16.1 (K), D17.1 (K), D18.1 (K), D19.1 (K), D20.1 (K), D21.1 (K), D22.1 (K), D23.1 (K), D24.1 (K), D25.1 (K), D26.1 (K), D27.1 (K), U1.11 (PA1)
ROW2: D28.1 (K), D29.1 (K), D30.1 (K), D31.1 (K), D32.1 (K), D33.1 (K), D34.1 (K), D35.1 (K), D36.1 (K), D37.1 (K), D38.1 (K), D39.1 (K), D40.1 (K), U1.12 (PA2)
ROW3: D41.1 (K), D42.1 (K), D43.1 (K), D44.1 (K), D45.1 (K), D46.1 (K), D47.1 (K), D48.1 (K), D49.1 (K), D50.1 (K), D51.1 (K), D52.1 (K), D53.1 (K), U1.13 (PA3)
SBU1: D57.2 (IO2), D57.9 (NC_3), J3.A8 (SBU1)
SBU2: D56.5 (IO4), D56.6 (NC_1), J3.B8 (SBU2)
XTAL1: C56.2, U1.5 (PF0), Y1.1
XTAL2: C53.2, U1.6 (PF1), Y1.3

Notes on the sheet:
USB-C
Crystal
MCU
Reset
5v to 3.3v
RGB matrix & caps, 13x4
Extra pins
Button matrix, 13x4
Audio
Mounts

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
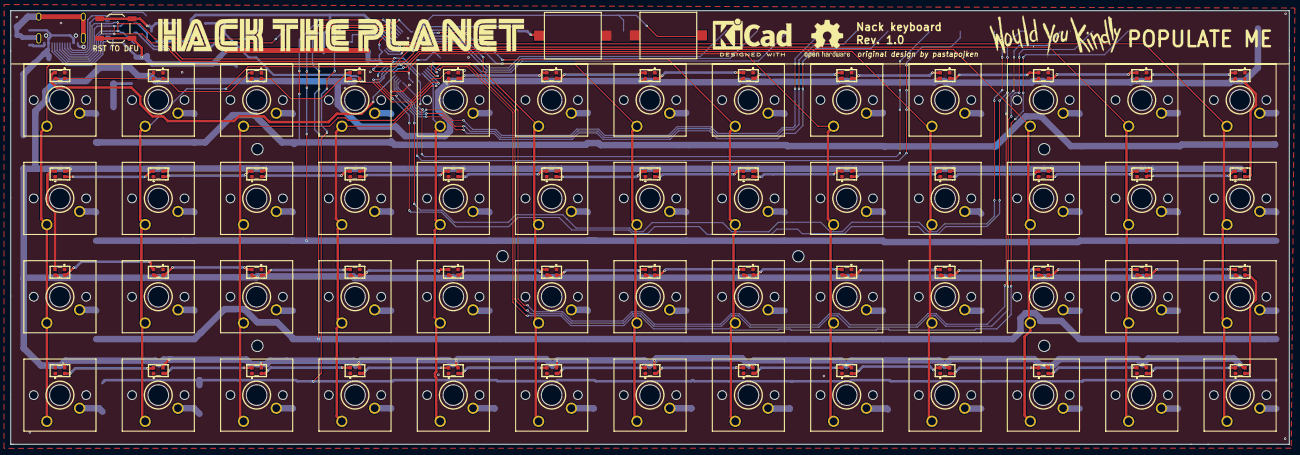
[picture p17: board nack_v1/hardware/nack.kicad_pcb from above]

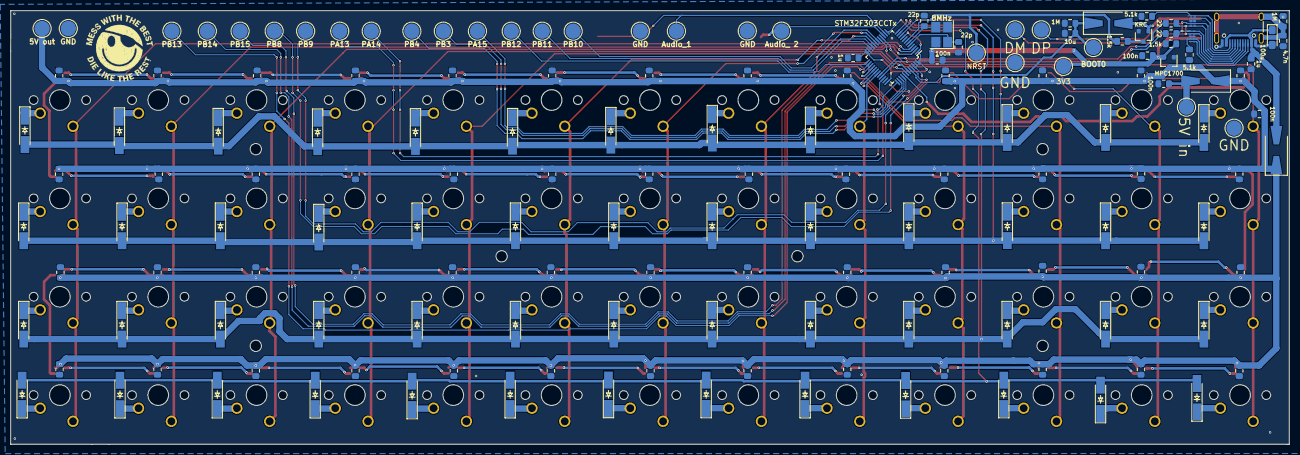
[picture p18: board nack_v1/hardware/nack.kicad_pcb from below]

Board: 2 copper layers, 247.7 x 84.0 mm, 273 parts (160 on the bottom side), 156 nets.
